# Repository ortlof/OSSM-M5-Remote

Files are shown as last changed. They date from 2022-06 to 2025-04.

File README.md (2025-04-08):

# Project OSSM M5 REMOTE
## Overview of the OSSM-M5-Remote

A Remote Control Platform for all ESP Controlled Sex Toys,with a focus on the [OSSM](https://github.com/KinkyMakers/OSSM-hardware) and related toys.

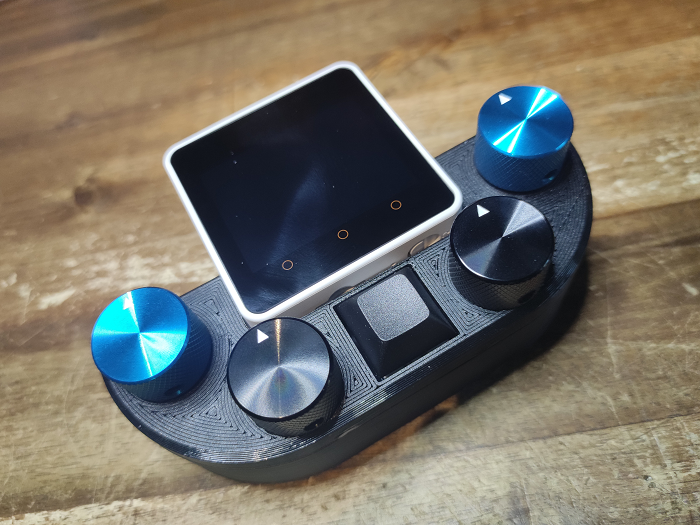
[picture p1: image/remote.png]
Final Addon Remote


Intially developed for the OSSM Project: 
https://github.com/KinkyMakers/OSSM-hardware

To help with development and design join the KinkyMakers Discord: https://discord.gg/MmpT9xE . Be sure to say hello in the #m5-remote channel. 

## !!! It does not Work with the Official OSSM Firmware !!!
This Branch is needed: https://github.com/ortlof/OSSM-Stroke

The Cable remote is obsolete with this firmware. If you want to go back you need to flash the OSSM orginal firmware back.

You can Easy flash the OSSM Mainboard with this [Online Flasher](https://openlust.org/lust-remote/lustremote-firmware/).

## Supported in this version of the M5 remote:
| OSSM Machine | https://github.com/KinkyMakers/OSSM-hardware |

## Not Supported sex toys in this version

| EJECT | https://github.com/ortlof/EJECT-cum-tube-project | [A Work in Progress]

# Build the OSSM M5 Remote Yourself

### Assembly instructions: [Klick Here !](Assembly.md)

## Bill Of Materials for sourcing Electrical Components

All M5Stack Core2 and CoreS3 are supported Now.

BOM is on Octopart for Easy Sourcing: https://octopart.com/bom-tool/rURYMuwB

PCB Files are located in the /OSSM-M5-Remote/Hardware/PCB folder if you want to make one yourself or use a different manufacturer other than PCBWay.

## Additional parts needed that are not PCB:  

| Quantity | Part | Sourcing EU | Price € |
|---|---|---|---|
| 1x | M5Stack CoreS3 SE | https://www.digikey.de/de/products/detail/m5stack-technology-co-ltd/K128-SE/23628221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 | 43 € |
| 2x | M3x25mm Hex Head Cap Bolt | https://www.amazon.de/Edelstahl-Innensechskant-Bolzenset-Eisenrahmen-Mechanischer-Innensechskantschraube-Mutternset/dp/B07PPFT871/ | 12,97 € |
| 4x | M3x20mm Hex Head Cap Bolt | Comes as part of the set mentioned above | " | 
| 4x | Heat Set inserts M3 | https://www.amazon.de/ruthex-Gewindeeinsatz-St%C3%BCck-Gewindebuchsen-Kunststoffteile/dp/B08BCRZZS3 | 8,99 € |
| 1x | 3,7v 2000mAh Lipo Batterie Size 34,5 mm x 10,6 mm x 56 mm | https://www.amazon.de/EEMB-103454-2AhLithium-Schutzplatine-Isolationsbeschichtung/dp/B08214DJLJ/ | 14,89 € |
| 4x | Encoder Knob Bought or 3D Printed | https://de.aliexpress.com/item/1005001394286414.html | 5 € |
| 1x | OSSM M5 Remote PCB | KinyMaker Discord #M5-Remote Channel or https://www.pcbway.com/project/shareproject/M5Stack_Core2_Remote_Plattform_2cb5bac0.html | 15 € |

--------------------------------------------

| Quantity | Part | Sourcing US | Price $ |
|---|---|---|---|
| 1x | M5Stack CoreS3 SE | https://www.digikey.de/de/products/detail/m5stack-technology-co-ltd/K128-SE/23628221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 | $47|
| 2x | M3x25mm Hex Head Cap Bolt | https://www.amazon.com/dp/B09NR8X2LV | $17.99 |
| 4x | M3x20mm Hex Head Cap Bolt | Comes as part of the set mentioned above | " | 
| 4x | Heat Set inserts M3 | https://www.amazon.com/ruthex-M3-Threaded-Inserts-RX-M3x5-7/dp/B08BCRZZS3 | $10.99 |
| 1x | 3.7v 2000mAh Lipo Battery Size 34.5 X 56 X 10.6 mm (The wires will need to be reversed in the connector on this one! See Assembly instructions for more info.) | https://www.amazon.com/EEMB-2000mAh-Battery-Rechargeable-Connector/dp/B08214DJLJ/ | $14.99 |
| 4x | Encoder Knob Bought or 3D Printed | https://www.aliexpress.us/item/3256801207971662.html?gatewayAdapt=deu2usa4itemAdapt | $5.00 |
| 1x | M5 Remote PCB | KinyMaker Discord #M5-Remote Channel or https://www.pcbway.com/project/shareproject/M5Stack_Core2_Remote_Plattform_2cb5bac0.html | $30.00 |

## 3D Printed Parts Needed:

| Quantity | Part | Information |
|---|---|---|
| 1x | Bottom.stl or Bottom_Adafruit_LIPO.stl or Bottom-Magnets.stl| There is a specific version for the wider Adafruit LIPO battery. Print with the base side facing down, 6 walls 20% Infill | 
| 1x | TOP-*-Keycap-Standoff.stl | Top Depends on your Keycap: Cherry or DSA (DSA is wider) | 
| 4x | M5_Remote_Knob_Customizable.scad | If you go for the 3d Printed knobs |

Filament - A good quality PLA works well. While there are no threads it is recommended that your printer is well calibrated.  

## Operation, or how do I use it?

1. Power on the OSSM and let it home.
2. Power on the OSSM M5 Remote.
3. Press the left encoder to select 'Connect'
4. You can verify it is connected by looking in the top left corner, it should say 'connected'.
5. You can now begin use. You'll need to set the speed, depth and stroke to more than 0 and press the middle key to start. Start the speed out slow.

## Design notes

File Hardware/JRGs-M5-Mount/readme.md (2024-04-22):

# JRGs M5 Mount

Hardware needed: 

| Quantity | Part |
|---|---|
| 2x | m3x12 Hex Head Cap Bolt |
| 2x | m5x20 Hex Head Cap Bolt |
| 2x | T-Slot Nut M5 | 

Print Without Supports

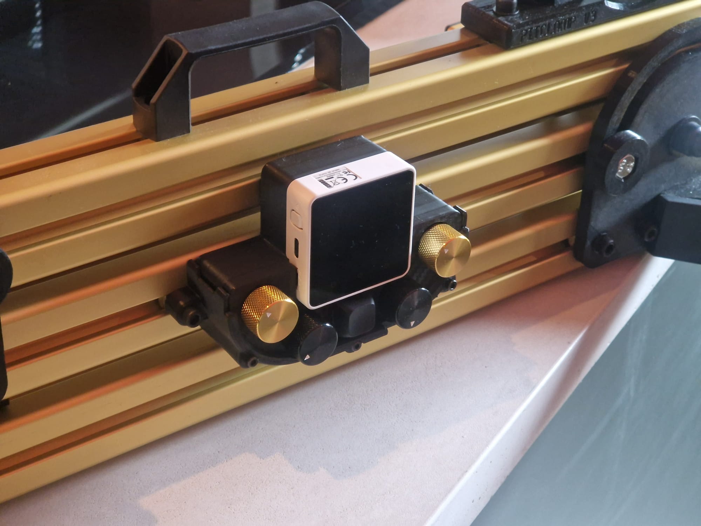
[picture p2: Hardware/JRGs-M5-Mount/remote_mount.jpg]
Mount


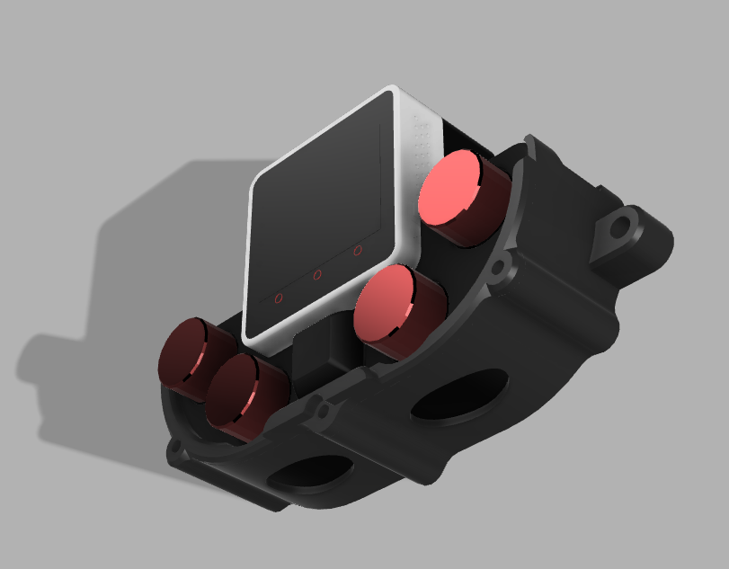
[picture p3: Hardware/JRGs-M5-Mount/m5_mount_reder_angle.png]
Mount


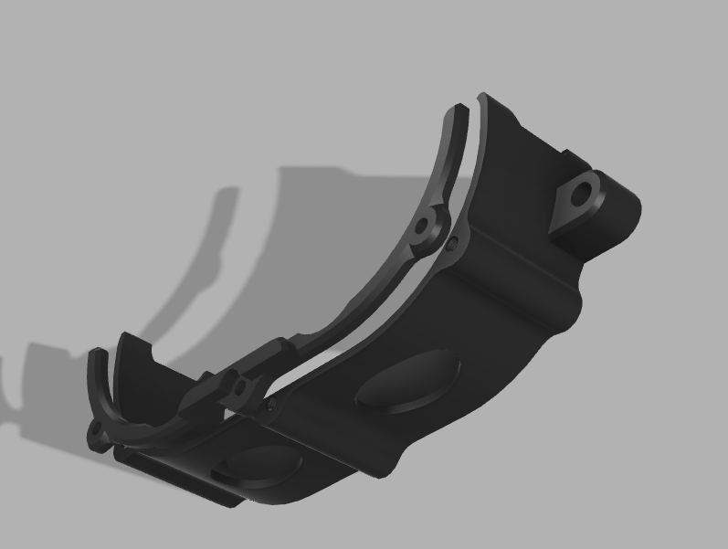
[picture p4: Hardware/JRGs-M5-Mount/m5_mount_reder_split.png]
Mount


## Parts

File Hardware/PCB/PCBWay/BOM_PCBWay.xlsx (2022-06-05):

 |  |  | T-H9W237108A
Item # | *Designator | *Qty | Manufacturer | *Mfg Part # | Description / Value | *Package/Footprint | Type | Your Instructions / Notes
1 | R1-R11 | 11 | Bourns | CR1206-JW-103ELF | Thick Film Resistors 10 kOhms 250 mW (1/4 W) | 3216 mm | SMD
Need a quick and accurante quote? Need an efficient production? Please read SMT Ordering Necessary Files & Info in 1 minute. Thank you very much! (https://www.pcbway.com/smt_ordering_guide.html)
Click for Instructions on How to Create a BOM (https://www.pcbway.com/blog/PCB_Assembly/How_to_Build_a_BOM__Bill_Of_Materials_.html)

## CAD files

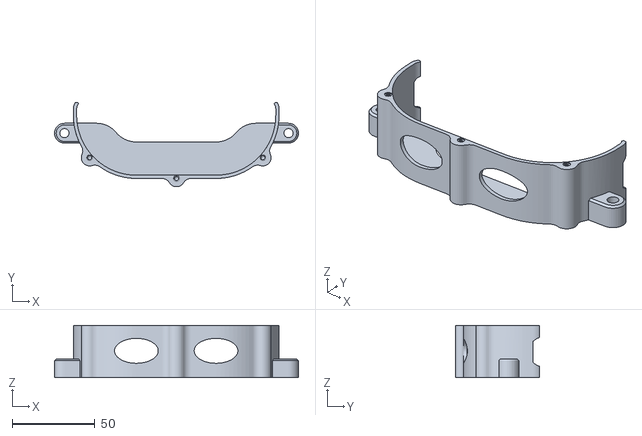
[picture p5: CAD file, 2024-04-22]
Hardware/JRGs-M5-Mount/Main_part_M5_mount.stl
147.1 x 50.9 x 31.6

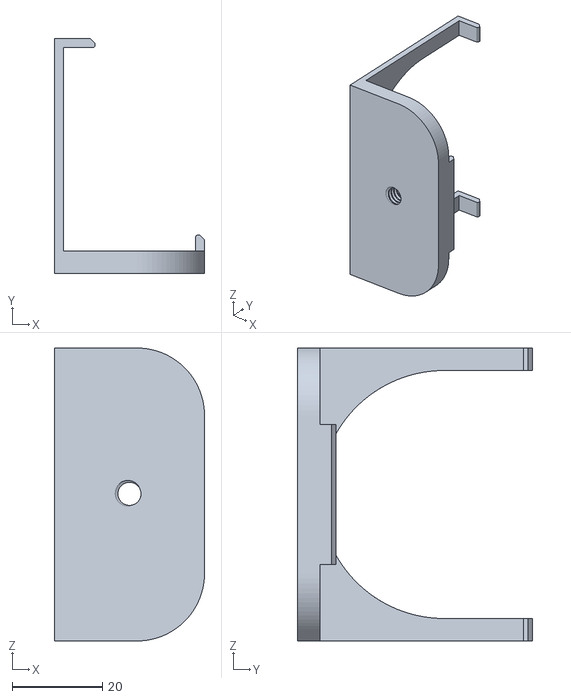
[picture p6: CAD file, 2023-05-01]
Hardware/Case/GHHOSS_tripod_mount/M5_Tripod_Holder_v3.stl
33.3 x 52.1 x 65.0

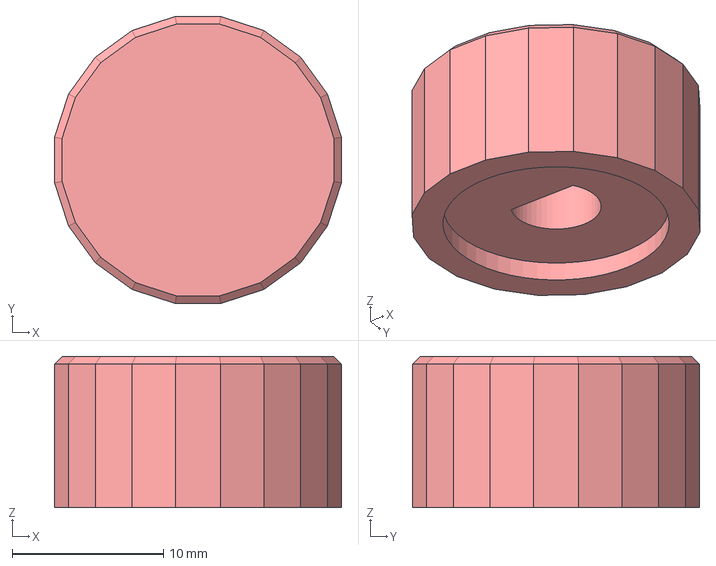
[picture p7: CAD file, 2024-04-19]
Hardware/Case/M5-Remote_knob_with_offset.step
19.0 x 19.0 x 10.0 mm

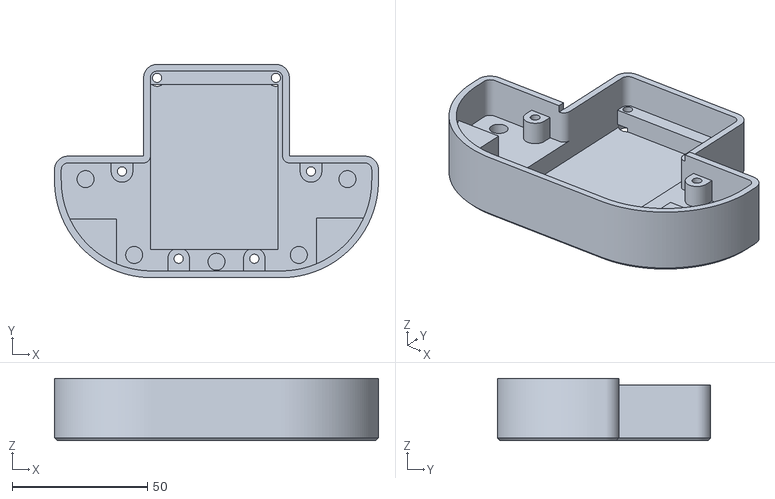
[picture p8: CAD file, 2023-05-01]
Hardware/Case/Bottom-Magnets.stl
120.0 x 79.0 x 23.0

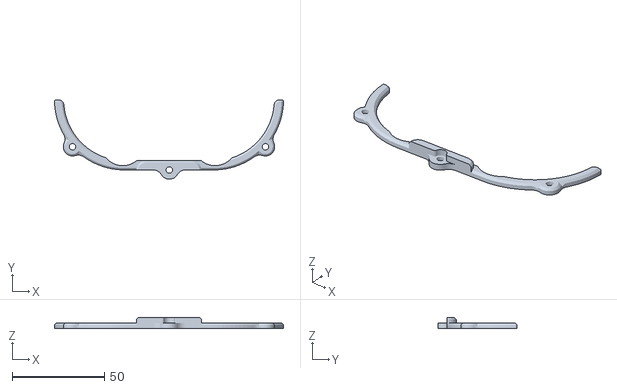
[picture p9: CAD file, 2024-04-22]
Hardware/JRGs-M5-Mount/top_part_m5_remote.stl
124.0 x 43.0 x 6.00

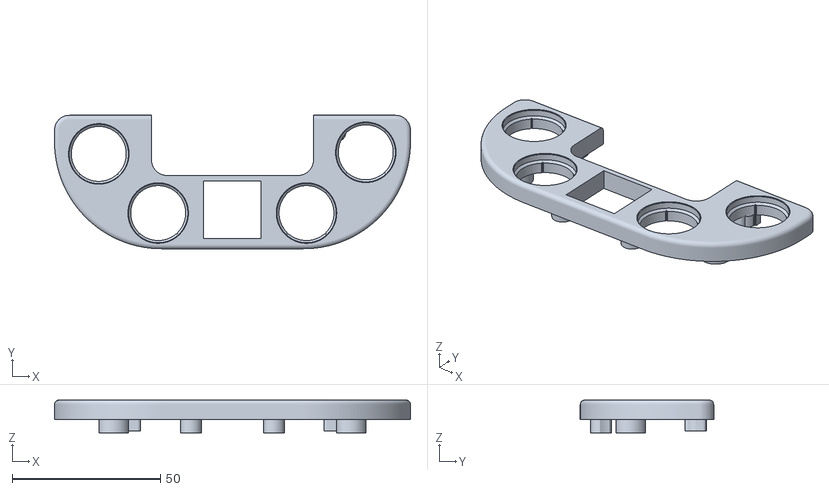
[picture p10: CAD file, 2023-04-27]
Hardware/Case/TOP-DSA-Keycap-Standoff_Bigger_Ecoder_Space.stl
120.0 x 45.0 x 11.1

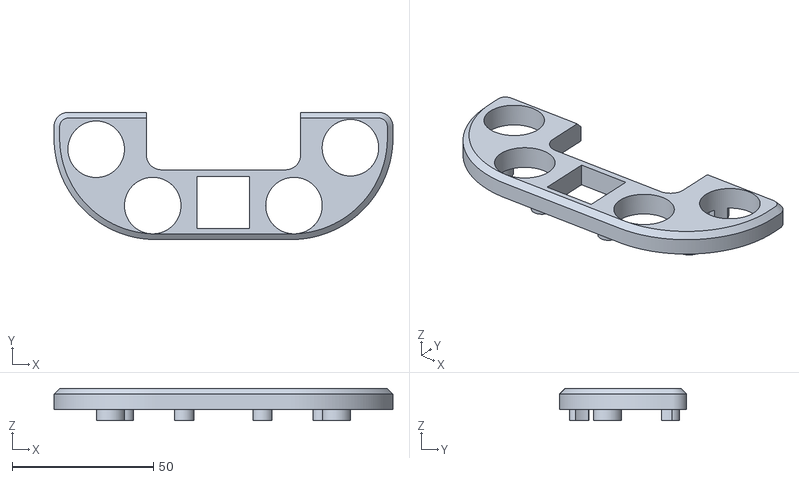
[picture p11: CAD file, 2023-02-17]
Hardware/Case/TOP-Cherry-Keycap-Standoff_Bigger_Ecoder_Space.stl
120.0 x 45.0 x 11.4

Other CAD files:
Hardware/Case/Bottom_Adafruit_Lipo.stl
Hardware/Case/TOP-DSA-Keycap-Standoff.stl
Hardware/Case/TOP-Cherry-Keycap-Standoff.stl
Hardware/Case/Bottom.stl
Hardware/Case/GHHOSS_tripod_mount/M5_Tripod_Holder_v3.f3d

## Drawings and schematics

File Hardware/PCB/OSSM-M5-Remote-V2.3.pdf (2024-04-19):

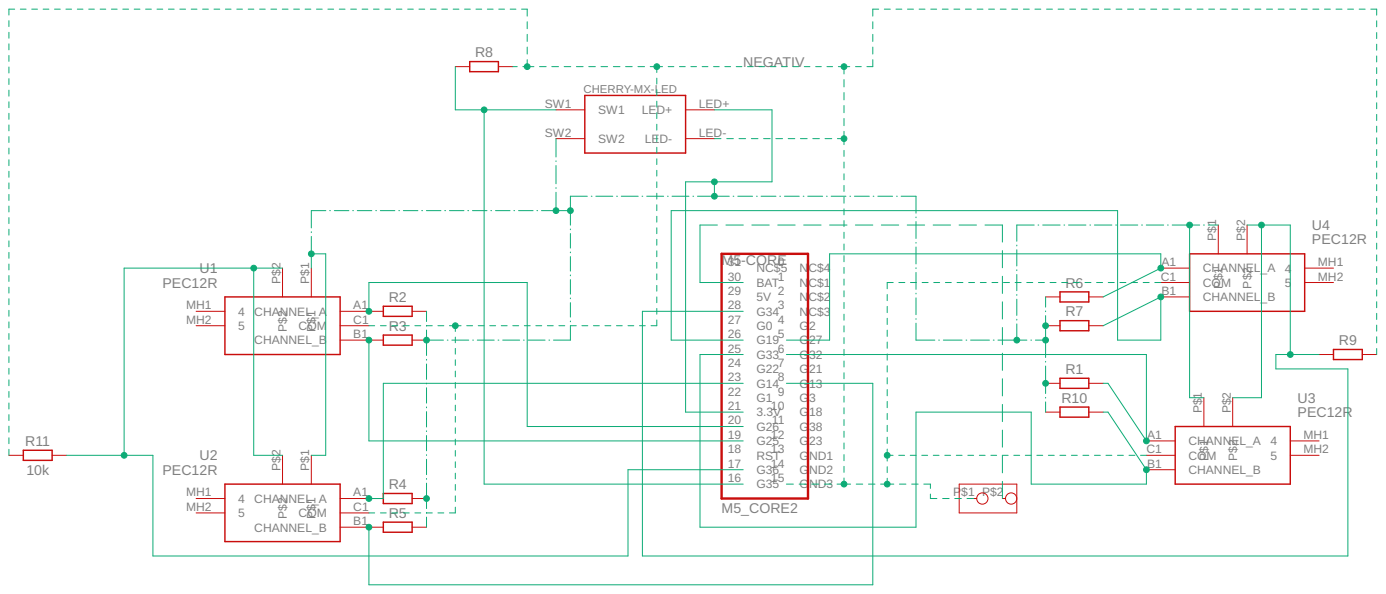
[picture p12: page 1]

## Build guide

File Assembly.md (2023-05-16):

# Assembling the OSSM M5 Remote

**Some important notes**
* Assembly will require soldering of small surface mount components in addition to through hole components. Be sure you have the proper tools and supplies:
    * Solder reflow oven or hot air gun with nozzles. You can use an old toaster oven as a reflow oven, just do not use it for food again after that.
    * Low temperature solder paste
    * Tweezers
    * Soldering iron
    * Rosin core solder
    * Flux
    * optional helping hands to hold the PCB while you solder
    * optional stencil provided by the PCB Manufacturer (not necessary but would make things easier)

* Due to a lack of standardisation in LIPO battery polarity it is important to verify how yours is configured. If the battery is reversed it will result in the CORE M5 Stack being damaged. You may have to reverse the female pins in the connector so they align with the expected polarity on the PCB.

## Solder the components

1. If you purchased a stencil from PCBWay/ Your chosen PCB Manufacturer, align it over the PCB and tape it in place. Add a blob of low temperature solder paste to the stencil and scrape it across the holes with a credit card or similar. When you lift the stencil away the PCB should now have solder paste on it in the correct places. Example photos below are from PCBWay and are not of the OSSM M5 Remote PCB  

solderPaste
solderPaste2
solderpaste3

If you did not purchase a stencil then you will need to very carefully coat the solder pads of the PCB with solder paste. It doesn't need a ton.

without_stencil  

Photo Credit Xue Ming. The amount of solder paste in the above photo is a little excessive.

2. Carefully place the 11 10k ohm resistors (Bourns CR1206-JW-103ELF) on the solder paste using tweezers. The polarity doesn't matter. Apply heat using a heat gun or reflow oven. The solder paste container will state what temperature to use.  

Resistors

3. Next, place the button encoders (Bourns PEC12R-4220F-S0024) at U1 and U4. Add flux to the pins and pad and solder the button encoders in place with a soldering iron.

4. Repeat the same for U2 and U3, adding flux and soldering the regular encoders (Bourns PEC12R-4220F-N0024)

5. The (Cherry MX1A-F1NN /  switch is soldered to the center position in the white square.

6. Next, the headers. Insert the headers from the front of the PCB (Amphenol Communications Solution 10129381-916001BLF), add a generous amount of flux to the back side and solder each pin.  

PCB-Soldered

7. Finally we will solder the battery connector (JST S2B-PH-K-S(LF)(SN)) on the back side of the PCB. The positive pin is the pin closest to the bottom edge of the PCB, the negative pin is the pin the closest to the top edge of the PCB.  

BatteryConnectorSoldered

8. Again pay special attention to the polarity of the Lithum battery you have, checking to see if the negative terminal of the battery connector will align with the negative pin of the connector on the PCB. Remove the wires from the battery terminal and reverse them if you need to (I had to, for example).

FlippingWires

## 3D printed parts

All parts are printed with 6 walls and 20% infill with a .04 nozzle. No supports and no brim (just a skirt).

A good quality PLA works well. While there are no threads it is recommended that your printer is well calibrated.  

* Be sure to choose the correct back to print based on the battery that you source 

    USA - Adafruit 485-2011 / or [Alternate](https://www.amazon.com/EEMB-2000mAh-Battery-Rechargeable-Connector/dp/B08214DJLJ/) uses 'Bottom_Adafruit_Lipo.stl' OR you can use 'Bottom-Magnets.stl' if you want to add 6 x 3mm magnets.

    Other countries - [RS Pro 1449405](https://uk.rs-online.com/web/p/speciality-size-rechargeable-batteries/1449405) uses 'Bottom.stl', or if you want to use magnets in the base you can use 'Bottom-Magnets.stl' that will accept 6 x 3mm magnets.

* You have options for the top depending on the keycap type you choose (cherry vs DSA). 

    If you chose to buy a DSA keycap go with 'TOP-DSA-Keycap-Standoff_Bigger_Ecoder_Space.stl'

    If you chose to buy a Cherry Keycap go with 'TOP-Cherry-Keycap-Standoff_Bigger_Ecoder_Space.stl'

* You can print encoder knobs or purchaes separate ones, 'M5_Remote_Knob_Customizable.scad'

* If you would like to mount the OSSM M5 remote to a mini tripod you can print the excellent holder by KinkyMakers Discord community member GHHOSS, the file is called  'M5_Tripod_Holder_v3.stl' and can be found in the 'GHHOSS_tripod_mount' folder.

* Finally you will add the M3 brass heatset inserts to the underside of the **TOP** piece.

## Final Assembly

1. Remove the M5 Core2 MIC/MPU Module from M5 Core2 Bottom, then unscrew the grey bottom and remove internal battery. Store the screws, the back and battery somewhere in case you want to use the M5 Stack Core2 for another project later.

2. Affix the battery to the bottom case with double sided tape.

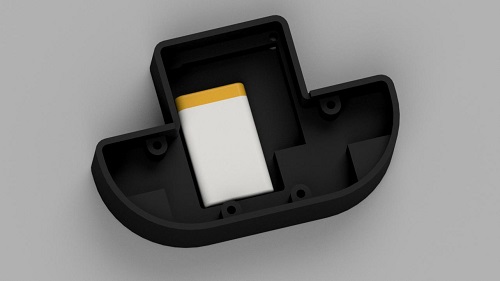
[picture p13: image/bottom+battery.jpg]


3. Connect Battery to PCB connector on the back side of the PCB.

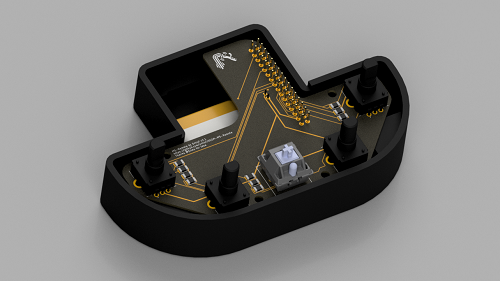
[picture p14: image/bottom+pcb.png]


4. Insert the PCB into Bottom case. 
AffixBattery

5. Connect the M5 Core2 to the headers on the PCB and fasten with two 25mm M3 Bolts to Case.

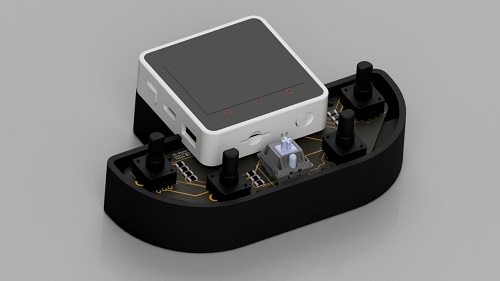
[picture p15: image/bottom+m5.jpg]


6. Put top on Remote and fasten with four M3 20mm Bolts to the Case.

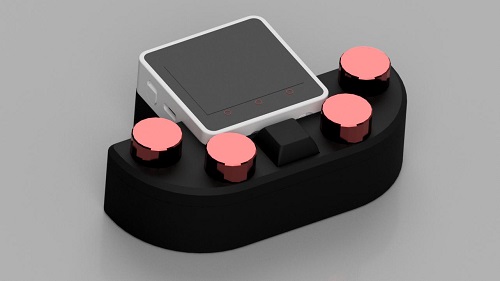
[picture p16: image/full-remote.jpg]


7. Install the Mx Cap and Encoder Knobs.

8. Charge the battery fully.

## Upload Software

1. Visit the [M5 website to download and install the drivers](https://docs.m5stack.com/en/core/core2) for the Core2 on your machine.

2. Clone or download this repository. If you download it as a zip, extract the files.  
**Note:** If you are one of the very small number of Version 1 PCB users, you will need to change your version to V1 in the config.h. The current version in this repository is V2.

3. Download Visual Studio Code and set up [PlatformIO](https://docs.platformio.org/en/latest/integration/ide/vscode.html#installation)  or [if you would prefer to watch a video](https://docs.platformio.org/en/latest/integration/ide/vscode.html#installation) - Thanks KinkyMakers Disord community admin Ka D'argo for the video!

Open the OSSM M5 Controller repository from step 2 in VS Code by clicking "File" > "Open Folder" and selecting the folder.

4. Once PlatformIO is set up you can select the M5 Core2 from your list of devices by clicking the 'Auto' button at the bottom center of the screen in the blue ribbon. If you aren't sure which device is the Core2 you can open DeviceManager on Windows and expand "Ports (COM & LPT)", then unplug the Core2 and plug it in again while keeping an eye on Device Manager to see what changes.

__Note:__
If you are one of the very small number of Version 1 PCB users, you will need to change your version to V1 in the config.h file. The current version in this GitHub repository is V2.

5. Click the upload button at the bottom left of the screen. The program will build then automatically upload to the M5 Core2. Once the software has succesfully uploaded you may disconnect the Core2 from your computer.

6. Next, Clone or download the M5 fork of the OSSM Stroke Engine from [here](https://github.com/ortlof/OSSM-Stroke) using the same method as mentioned in Step 2.

7. Open the OSSM Stroke repository from Step 5 in VS Code, again by clicking "File" > "Open Folder" and selecting the folder.

8. Now connect the OSSM board to your computer using a USB cable. You can look for it in DeviceManager the same way as you did in step 4. [You can also reference this link for help](https://github.com/KinkyMakers/OSSM-hardware/blob/master/OSSM%20PlatformIO%20Readme.md)

9. Click upload.

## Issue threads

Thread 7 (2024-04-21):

Ossm not using full stroke length

MarcoB979, 2024-04-21:
Seems to be a known bug and Imight have found a 'quick fix'. When in ossmconfig you have to setup max stroke. I have a 450mm rail and ended up setting the max stroke at 400. Also I set the max user speed to 300 (don't know if that also is making a difference). Then in the m5 remote code in main.cpp line 133 and 134 this is hard coded so you have to change it there too with the same values. Now I got the whole of the rail length with both depth and stroke and works just fine. Solution would be that  in main.cpp the values are not hard coded but transferred using a variable.

ortlof, 2025-06-02:
Sorry for not responding read it forgot it. I will check this but could be fixed in latest commits already.

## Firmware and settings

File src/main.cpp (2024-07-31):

#pragma GCC optimize ("Ofast")
#include <M5Unified.h>
#include <ESP32Encoder.h>
#include <esp_now.h>
#include <WiFi.h>
#include <PatternMath.h>
#include "OneButton.h"          //For Button Debounce and Longpress
#include "config.h"
#include <Arduino.h>
#include <Wire.h>
#include <lvgl.h>
#include <SPI.h>
#include "ui/ui.h"
#include <EEPROM.h>
#include "main.h"

#define LV_CONF_INCLUDE_SIMPLE
#include <lvgl.h>
#include <esp_timer.h>

constexpr int32_t HOR_RES=320;
constexpr int32_t VER_RES=240;

///////////////////////////////////////////
////
////  To Debug or not to Debug
////
///////////////////////////////////////////

// Uncomment the following line if you wish to print DEBUG info
#define DEBUG 

#ifdef DEBUG
#define LogDebug(...) Serial.println(__VA_ARGS__)
#define LogDebugFormatted(...) Serial.printf(__VA_ARGS__)
#else
#define LogDebug(...) ((void)0)
#define LogDebugFormatted(...) ((void)0)
#endif

#define OFF 0.0
#define ON 1.0

// Screens 

#define ST_UI_START 0
#define ST_UI_HOME 1

#define ST_UI_MENUE 10
#define ST_UI_PATTERN 11
#define ST_UI_Torqe 12
#define ST_UI_EJECTSETTINGS 13

#define ST_UI_SETTINGS 20

int st_screens = ST_UI_START;



// Menü States

#define CONNECT 0
#define HOME 1
#define MENUE 2
#define MENUE2 3
#define TORQE 4
#define PATTERN_MENUE 5
#define PATTERN_MENUE2 6
#define PATTERN_MENUE3 7
#define CUM_MENUE 20

int menuestatus = CONNECT;

// EEPROM Area:

#define EJECT 0
#define DARKMODE 1
#define VIBRATE 2
#define LEFTY 6

bool eject_status = false;
bool dark_mode = false;
bool vibrate_mode = true;
bool touch_home = false;
bool touch_disabled = false;

// Command States
#define CONN 0
#define SPEED 1
#define DEPTH 2
#define STROKE 3
#define SENSATION 4
#define PATTERN 5
#define TORQE_F 6
#define TORQE_R 7
#define OFF 10
#define ON  11
#define SETUP_D_I 12
#define SETUP_D_I_F 13
#define REBOOT 14

#define CUMSPEED 20
#define CUMTIME 21
#define CUMSIZE   22
#define CUMACCEL  23

#define CONNECT 88
#define HEARTBEAT 99

int displaywidth;
int displayheight;
int progheight = 30;
int distheight = 10;
int S1Pos;
int S2Pos;
int S3Pos;
int S4Pos;
bool rstate = false;
int pattern = 2;
char patternstr[20];
bool onoff = false;


long speedenc = 0;
long depthenc = 0;
long strokeenc = 0;
long sensationenc = 0;
long torqe_f_enc = 0;
long torqe_r_enc = 0;
long cum_t_enc = 0;
long cum_si_enc =0;
long cum_s_enc = 0;
long cum_a_enc = 0;
long encoder4_enc = 0;

extern float maxdepthinmm = 400.0;
extern float speedlimit = 600;
int speedscale = -5;

float speed = 0.0;
float depth = 0.0;
float stroke = 0.0;
float sensation = 0.0;
float torqe_f = 100.0;
float torqe_r = -180.0;
float cum_time = 0.0;
float cum_speed = 0.0;
float cum_size = 0.0;
float cum_accel = 0.0;

ESP32Encoder encoder1;
ESP32Encoder encoder2;
ESP32Encoder encoder3;
ESP32Encoder encoder4;

// Variable to store if sending data was successful
String success;

float out_esp_speed;
float out_esp_depth;
float out_esp_stroke;
float out_esp_sensation;
float out_esp_pattern;
bool out_esp_rstate;
bool out_esp_connected;
int out_esp_command;
float out_esp_value;
int out_esp_target;

float incoming_esp_speed;
float incoming_esp_depth;
float incoming_esp_stroke;
float incoming_esp_sensation;
float incoming_esp_pattern;
bool incoming_esp_rstate;
bool incoming_esp_connected;
bool incoming_esp_heartbeat;
int incoming_esp_target;

typedef struct struct_message {
  float esp_speed;
  float esp_depth;
  float esp_stroke;
  float esp_sensation;
  float esp_pattern;
  bool esp_rstate;
  bool esp_connected;
  bool esp_heartbeat;
  int esp_command;
  float esp_value;
  int esp_target;
} struct_message;

bool Ossm_paired = false;

struct_message outgoingcontrol;
struct_message incomingcontrol;

esp_now_peer_info_t peerInfo;
uint8_t OSSM_Address[] = {0xFF, 0xFF, 0xFF, 0xFF, 0xFF, 0xFF}; // Broadcast to all ESP32s, upon connection gets updated to the actual address

#define HEARTBEAT_INTERVAL 5000/portTICK_PERIOD_MS	// 5 seconds

// Bool

bool EJECT_On = false;
bool OSSM_On = false;

#define EEPROM_SIZE 200

// Tasks:

TaskHandle_t eRemote_t  = nullptr;  // Esp Now Remote Task

void espNowRemoteTask(void *pvParameters); // Handels the EspNow Remote
bool connectbtn(); //Handels Connectbtn
int64_t touchmenue();
void vibrate();
void mxclick();
bool mxclick_short_waspressed = false;
void mxlong();
bool mxclick_long_waspressed = false;
void click2();
bool click2_short_waspressed = false;
void click3();
bool click3_short_waspressed = false;

lv_display_t *display;
lv_indev_t *indev;

static lv_draw_buf_t *draw_buf1;
static lv_draw_buf_t *draw_buf2;

// Display flushing
void my_display_flush(lv_display_t *disp, const lv_area_t *area, uint8_t *px_map) {
  uint32_t w = (area->x2 - area->x1 + 1);
  uint32_t h = (area->y2 - area->y1 + 1);

  lv_draw_sw_rgb565_swap(px_map, w*h);
  M5.Display.pushImageDMA<uint16_t>(area->x1, area->y1, w, h, (uint16_t *)px_map);
  lv_disp_flush_ready(disp);
}

uint32_t my_tick_function() {
  return (esp_timer_get_time() / 1000LL);
}

void my_touchpad_read(lv_indev_t * drv, lv_indev_data_t * data) {
  M5.update();
  auto count = M5.Touch.getCount();

  if ( count == 0 ) {
    data->state = LV_INDEV_STATE_RELEASED;
  } else {
    auto touch = M5.Touch.getDetail(0);
    data->state = LV_INDEV_STATE_PRESSED; 
    data->point.x = touch.x;
    data->point.y = touch.y;
  }
}

static void event_cb(lv_event_t *e)
{
  lv_event_code_t code = lv_event_get_code(e);
  lv_obj_t *label = reinterpret_cast<lv_obj_t *>(lv_event_get_user_data(e));

  switch (code)
  {
  case LV_EVENT_PRESSED:
    lv_label_set_text(label, "The last button event:\nLV_EVENT_PRESSED");
    break;
  case LV_EVENT_CLICKED:
    lv_label_set_text(label, "The last button event:\nLV_EVENT_CLICKED");
    break;
  case LV_EVENT_LONG_PRESSED:
    lv_label_set_text(label, "The last button event:\nLV_EVENT_LONG_PRESSED");
    break;
  case LV_EVENT_LONG_PRESSED_REPEAT:
    lv_label_set_text(label, "The last button event:\nLV_EVENT_LONG_PRESSED_REPEAT");
    break;
  default:
    break;
  }
}



void OnDataSent(const uint8_t *mac_addr, esp_now_send_status_t status) {
}

void OnDataRecv(const uint8_t * mac, const uint8_t *incomingData, int len) {
  memcpy(&incomingcontrol, incomingData, sizeof(incomingcontrol));

  if(incomingcontrol.esp_target == M5_ID && Ossm_paired == false){

    // Remove the existing peer (0xFF:0xFF:0xFF:0xFF:0xFF:0xFF)
    esp_err_t result = esp_now_del_peer(peerInfo.peer_addr);

    if (result == ESP_OK) {

      memcpy(OSSM_Address, mac, 6); //get the mac address of the sender
      
      // Add the new peer
      memcpy(peerInfo.peer_addr, OSSM_Address, 6);
      if (esp_now_add_peer(&peerInfo) == ESP_OK) {
        LogDebugFormatted("New peer added successfully, OSSM addresss : %02X:%02X:%02X:%02X:%02X:%02X\n", OSSM_Address[0], OSSM_Address[1], OSSM_Address[2], OSSM_Address[3], OSSM_Address[4], OSSM_Address[5]);
        Ossm_paired = true;
      }
      else {
        LogDebug("Failed to add new peer");
      }
    }
    else {
      LogDebug("Failed to remove peer");
    }

    
    if(incomingcontrol.esp_speed > speedlimit){
      speedlimit = 600;
    } else (
    speedlimit = incomingcontrol.esp_speed);
    LogDebug(speedlimit);
    maxdepthinmm = incomingcontrol.esp_depth;
    LogDebug(maxdepthinmm);
    pattern = incomingcontrol.esp_pattern;
    LogDebug(pattern);
    outgoingcontrol.esp_target = OSSM_ID;
    
    result = esp_now_send(OSSM_Address, (uint8_t *) &outgoingcontrol, sizeof(outgoingcontrol));
    LogDebug(result);
    
    if (result == ESP_OK) {
      Ossm_paired = true;
      lv_label_set_text(ui_connect, "Connected");
      lv_scr_load_anim(ui_Home, LV_SCR_LOAD_ANIM_FADE_ON,20,0,false);
    }
  }
  switch(incomingcontrol.esp_command)
    {
    case OFF: 
    {
    OSSM_On = false;
    }
    break;
    case ON:
    {
    OSSM_On = true;
    }
    break;
    }
}

//Sends Commands and Value to Remote device returns ture or false if sended
bool SendCommand(int Command, float Value, int Target){
  
  if(Ossm_paired == true){

    outgoingcontrol.esp_connected = true;
    outgoingcontrol.esp_command = Command;
    outgoingcontrol.esp_value = Value;
    outgoingcontrol.esp_target = Target;
    esp_err_t result = esp_now_send(OSSM_Address, (uint8_t *) &outgoingcontrol, sizeof(outgoingcontrol));
  
    if (result == ESP_OK) {
      return true;
    } 
    else {
      delay(20);
      esp_err_t result = esp_now_send(OSSM_Address, (uint8_t *) &outgoingcontrol, sizeof(outgoingcontrol));
      return false;
    }
  }
}

void connectbutton(lv_event_t * e)
{
    if(!Ossm_paired){
      outgoingcontrol.esp_command = HEARTBEAT;
      outgoingcontrol.esp_heartbeat = true;
      outgoingcontrol.esp_target = OSSM_ID;
      esp_err_t result = esp_now_send(OSSM_Address, (uint8_t *) &outgoingcontrol, sizeof(outgoingcontrol));
    }
}

void savesettings(lv_event_t * e)
{
	if(lv_obj_get_state(ui_ejectaddon) == 1){
		EEPROM.writeBool(EJECT,true);
	} else if(lv_obj_get_state(ui_ejectaddon) == 0){
		EEPROM.writeBool(EJECT,false);
	}
  if(lv_obj_get_state(ui_darkmode) == 1){
		EEPROM.writeBool(DARKMODE,true);
	} else if(lv_obj_get_state(ui_darkmode) == 0){
		EEPROM.writeBool(DARKMODE,false);
	}
  if(lv_obj_get_state(ui_vibrate) == 1){
		EEPROM.writeBool(VIBRATE,true);
	} else if(lv_obj_get_state(ui_vibrate) == 0){
		EEPROM.writeBool(VIBRATE,false);
	}
  if(lv_obj_get_state(ui_lefty) == 1){
		EEPROM.writeBool(LEFTY,true);
	} else if(lv_obj_get_state(ui_lefty) == 0){
		EEPROM.writeBool(LEFTY,false);
	}
  EEPROM.commit();
  delay(100);
  ESP.restart();
}

void screenmachine(lv_event_t * e)
{
  if (lv_scr_act() == ui_Start){
    st_screens = ST_UI_START;
  } else if (lv_scr_act() == ui_Home){
    st_screens = ST_UI_HOME;
    speed = lv_slider_get_value(ui_homespeedslider);
    LogDebug(speedenc);
    LogDebug(speed);
    speedenc =  fscale(0.5, speedlimit, 0, Encoder_MAP, speed, 0);
    encoder1.setCount(speedenc); 
    LogDebug(speedenc);

    lv_slider_set_range(ui_homedepthslider, 0, maxdepthinmm);
    depth = lv_slider_get_value(ui_homedepthslider);       
    depthenc =  fscale(0, maxdepthinmm, 0, Encoder_MAP, depth, 0);
    encoder2.setCount(depthenc);

    lv_slider_set_range(ui_homestrokeslider, 0, maxdepthinmm);        
    stroke = lv_slider_get_value(ui_homestrokeslider);    
    strokeenc =  fscale(0, maxdepthinmm, 0, Encoder_MAP, stroke, 0);
    encoder3.setCount(strokeenc);

    sensation = lv_slider_get_value(ui_homesensationslider);
    sensationenc =  fscale(-100, 100, (Encoder_MAP/2*-1), (Encoder_MAP/2), sensation, 0);
    encoder4.setCount(sensationenc);        
            
  } else if (lv_scr_act() == ui_Menue){
    st_screens = ST_UI_MENUE;
  } else if (lv_scr_act() == ui_Pattern){
    st_screens = ST_UI_PATTERN;
  } else if (lv_scr_act() == ui_Torqe){
    st_screens = ST_UI_Torqe;
    torqe_f = lv_slider_get_value(ui_outtroqeslider);
    torqe_f_enc = fscale(50, 200, 0, Encoder_MAP, torqe_f, 0);
    encoder1.setCount(torqe_f_enc);

    torqe_r = lv_slider_get_value(ui_introqeslider);
    torqe_r_enc = fscale(20, 200, 0, Encoder_MAP, torqe_r, 0);
    encoder4.setCount(torqe_r_enc);

  } else if (lv_scr_act() == ui_EJECTSettings){
    st_screens = ST_UI_EJECTSETTINGS;
  } else if (lv_scr_act() == ui_Settings){
    st_screens = ST_UI_SETTINGS;
  }
}

void ejectcreampie(lv_event_t * e){
  if(EJECT_On == true){
    lv_obj_clear_state(ui_HomeButtonL, LV_STATE_CHECKED);
    EJECT_On = false;
  } else if(EJECT_On == false){
    lv_obj_add_state(ui_HomeButtonL, LV_STATE_CHECKED);
    EJECT_On = true;
  } 
}

void savepattern(lv_event_t * e){
  pattern = lv_roller_get_selected(ui_PatternS);
  lv_roller_get_selected_str(ui_PatternS,patternstr,0);
  lv_label_set_text(ui_HomePatternLabel,patternstr);
  LogDebug(pattern);
  float patterns = pattern;
  SendCommand(PATTERN, patterns, OSSM_ID);
}

void homebuttonmevent(lv_event_t * e){
  LogDebug("HomeButton");
  if(OSSM_On == false){
    SendCommand(ON, 0.0, OSSM_ID);
  } else if(OSSM_On == true){
    SendCommand(OFF, 0.0, OSSM_ID);
  }
}

void setupDepthInter(lv_event_t * e){
    SendCommand(SETUP_D_I, 0.0, OSSM_ID);
}

void setupdepthF(lv_event_t * e){
    SendCommand(SETUP_D_I_F, 0.0, OSSM_ID);
}

void setup(){
  auto cfg = M5.config();
  M5.begin(cfg);
  EEPROM.begin(EEPROM_SIZE);

  M5.Power.setChargeCurrent(BATTERY_CHARGE_CURRENT);
  LogDebug("\n Starting");      // Start LogDebug 

  WiFi.mode(WIFI_STA);
  LogDebug(WiFi.macAddress());

  // Init ESP-NOW
  if (esp_now_init() != ESP_OK) {
    Serial.println("Error initializing ESP-NOW");
  }
  // Once ESPNow is successfully Init, we will register for Send CB to
  // get the status of Trasnmitted packet
  esp_now_register_send_cb(OnDataSent);

  // register peer
  peerInfo.channel = 0;  
  peerInfo.encrypt = false;
  // register first peer  
  memcpy(peerInfo.peer_addr, OSSM_Address, 6);
  if (esp_now_add_peer(&peerInfo) != ESP_OK){
    Serial.println("Failed to add peer");
  }
  // Register for a callback function that will be called when data is received
  esp_now_register_recv_cb(OnDataRecv);

  xTaskCreatePinnedToCore(espNowRemoteTask,      /* Task function. */
                            "espNowRemoteTask",  /* name of task. */
                            3096,               /* Stack size of task */
                            NULL,               /* parameter of the task */
                            5,                  /* priority of the task */
                            &eRemote_t,         /* Task handle to keep track of created task */
                            0);                 /* pin task to core 0 */
  delay(200);
  
  encoder1.attachHalfQuad(ENC_1_CLK, ENC_1_DT);
  encoder2.attachHalfQuad(ENC_2_CLK, ENC_2_DT);
  encoder3.attachHalfQuad(ENC_3_CLK, ENC_3_DT);
  encoder4.attachHalfQuad(ENC_4_CLK, ENC_4_DT);
  Button1.attachClick(mxclick);
  Button1.attachLongPressStop(mxlong);
  Button2.attachClick(click2);
  Button3.attachClick(click3);

    //****Load EEPROOM:
  eject_status = EEPROM.readBool(EJECT);
  dark_mode = EEPROM.readBool(DARKMODE);
  vibrate_mode = EEPROM.readBool(VIBRATE);
  touch_home = EEPROM.readBool(LEFTY);

  // Initialize `disp_buf` display buffer with the buffer(s).
  // lv_draw_buf_init(&draw_buf, LV_HOR_RES_MAX, LV_VER_RES_MAX);
  M5.Display.setEpdMode(epd_mode_t::epd_fastest); // fastest but very-low quality.
  if (M5.Display.width() < M5.Display.height())
  { /// Landscape mode.
  M5.Display.setRotation(M5.Display.getRotation() ^ 1);
  }
  
  lv_init();
  lv_tick_set_cb(my_tick_function);

  display = lv_display_create(HOR_RES, VER_RES);
  lv_display_set_flush_cb(display, my_display_flush);

  static lv_color_t buf1[HOR_RES * 15]; 
  lv_display_set_buffers(display, buf1, nullptr, sizeof(buf1), LV_DISPLAY_RENDER_MODE_PARTIAL);

  indev = lv_indev_create();
  lv_indev_set_type(indev, LV_INDEV_TYPE_POINTER);
  lv_indev_set_read_cb(indev, my_touchpad_read);
  ui_init();  

  if(eject_status == true){
  lv_obj_add_state(ui_ejectaddon, LV_STATE_CHECKED);
  lv_obj_clear_state(ui_EJECTSettingButton, LV_STATE_DISABLED);
  lv_obj_clear_state(ui_HomeButtonL, LV_STATE_DISABLED);
  }
  if(dark_mode == true){
  lv_obj_add_state(ui_darkmode, LV_STATE_CHECKED);
  }
  if(vibrate_mode == true){
  lv_obj_add_state(ui_vibrate, LV_STATE_CHECKED);
  }
  if(touch_home == true){
  lv_obj_add_state(ui_lefty, LV_STATE_CHECKED);
  }
  lv_roller_set_selected(ui_PatternS,2,LV_ANIM_OFF);
  lv_roller_get_selected_str(ui_PatternS,patternstr,0);
  lv_label_set_text(ui_HomePatternLabel,patternstr);


}
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

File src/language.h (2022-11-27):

//EN
// Language
#define T_HEADER            "OSSM Remote"
#define T_BLANK             ""
#define T_MENUE             "Menu"
#define T_DEMO              "Demo"
#define T_CONNECT           "Connect"
#define T_SETTINGS          "Settings"
#define T_MOTD              "Welcome to OSSM M5 Remote"
#define T_BATT              "Battery"
#define T_CREAMPIE          "Creampie"
#define T_START             "Start/Stop"
#define T_CUM               "Cum"
#define T_HOME              "Home"
#define T_MEN1              "Up"
#define T_MEN2              "Down"
#define T_SPEED             "Speed:"
#define T_DEPTH             "Depth:"
#define T_MM                " mm"
#define T_STROKE            "Stroke:"
#define T_SENSATION         "Sensation:"
#define T_SETUP_DEPTH_I     "Set Depth Interactively"
#define T_SETUP_DEPTH_F     "Set Depth Fancy"
#define T_SELECT_PATTERN    "Select Pattern"
#define T_PATTERN_Button    "Select Pattern \n Menue"
#define T_RESTART           "Restart"
#define T_SETUP_TORQE       "Setup Torque"
#define T_OUT_TORQE         "Outward Torque:"
#define T_IN_TORQE          "Inward Torque:"
#define T_EJECT_SETTINGS    "EJECT Settings"
#define T_EJECT             "EJECT"
#define T_SAVE              "Save"
#define T_LOW               "Low"
#define T_HIGH              "High"
#define T_DARKM             "Dark Mode"
#define T_VIBRATE           "Vibrate"
#define T_TOUCHSETTING      "Touch Disabled"


#define T_Patterns          "Pattern:"
#define T_SimpleStroke      "Simple Stroke"
#define T_TeasingPounding   "Teasing or Pounding"
#define T_RoboStroke        "Robo Stroke"
#define T_HalfnHalf         "Half 'n' Half"
#define T_Deeper            "Deeper"
#define T_StopNGo           "Stop'n'Go"
#define T_Insist            "Insist"
#define T_JackHammer        "Jack Hammer"
#define T_StrokeNibbler     "Stroke Nibbler"

#define T_CUM_SPEED         "CUM Speed"
#define T_CUM_TIME          "CUM Time"
#define T_CUM_Volume        "CUM Volume"
#define T_CUM_Accel         "CUM Force"

#define T_FUCKS_MIN         " F/m"

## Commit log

2022-03-27 Pattern Menue
    [Body.3mf, Knob.3mf, top.3mf]
2022-03-28 Updated f3ds und pcb export
    [BOM.xlsx, Body.3mf, Case-Body.3mf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]
2022-05-06 Readme, PCB, BOM
    Changed Readme, Removed Old BOM, Added PCB PDF Printout
    [BOM.xlsx]
2022-06-05 Final v2 PcB Desing
    Pin Changes in v2 PcB
    [BOM_PCBWay.xlsx, OSSM-M5-Remote-PCB-V2.f3z, OSSM-M5-Remote-V2-Centroid.csv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]
2022-07-14 Changed Case Files / Changed config.h
    Moved Pinlayout to config.h
    [Bottom.stl, Case-Body.3mf, Case-Top-With-Knobs.3mf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]
2022-07-17 Fixed Things
    Added MX/DSA keycap stl
    Fixed PCB hole size on JST Header
    Exported Newest f3z version
    [TOP-Cherry-Keycap.stl, TOP-DSA-Keycap.stl]
2022-07-21 Fixed PCB | Changed Case
    [TOP-Cherry-Keycap.stl, TOP-DSA-Keycap.stl]
2022-07-24 Standoff Fix and add scad for knob
    [M5_Remote_Knob_Customizable.scad, TOP-Cherry-Keycap-Standoff.stl, TOP-Cherry-Keycap.stl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]
2022-07-25 Fix Pattern Menue from Sapph1re Dra90n
    [main.cpp]
2022-07-31 Fixed Platformio & Adafruit Lipo case
    [Bottom_Adafruit_Lipo.stl]
2022-08-08 Buttons / Encoder
    Buttons & Encoder Online on Home and Menue. No activ use possible.
2022-08-11 Fixed Library Issue + More Screens Running
    [main.cpp]
2022-08-12 Fixed Pinout for V1 PCB's
2022-11-27 Added Line 134 scaling for speed
    Added Speedscale for better mapping of speed encoder
2023-01-26 Increase default charge current from 100mA to 960mA
2023-01-27 Change default charging current back to 100mA, but keep config
2023-02-17 Update on 3D Prints
    [TOP-Cherry-Keycap-Standoff_Bigger_Ecoder_Space.stl, TOP-DSA-Keycap-Standoff_Bigger_Ecoder_Space.stl]
2023-04-27 Add M5 Tripod Hodler
    Thanks to GHHoss
    [M5_Tripod_Holder_v2.3mf, M5_Tripod_Holder_v2.stl, TOP-DSA-Keycap-Standoff_Bigger_Ecoder_Space.stl]
2023-05-01 Update Tripod Holder & Fusion Export
    Fusion Export M5 Remote with Magnets
    [Bottom-Magnets.stl, M5_Tripod_Holder_v2.3mf, M5_Tripod_Holder_v2.stl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]
2023-05-14 expanding instructions
    Create assembly.md
    move a few headings from readme.md to assembly.md, add a US parts table
    to do: add pictures
2023-05-14 use instructions
    Added instructions for use as the current software requires a specific procedure to be followed to work correctly.
2023-05-15 Update Assembly.md
    Adding pictures and formatting changes
2023-05-15 Update README.md
    Linking the assembly instructions and clarifying points
2023-05-15 Update Assembly.md
    cleanup before PR
2023-06-03 V2.1 PCB Update
    Changed Silkscreen for Battery Pins
    Linked U3/U2 to enable change of pushbutton encoder place.
    [OSSM-M5-Remote-V2-PCB.f3z]
2023-06-10 Fix autoconnect Bug Remote.
    Fixed bug the Remotes autoconnects when running bevor the OSSM
    [main.cpp]
2023-06-15 Fix issue creampie button
2024-03-11 Fix Knob from DirkStrider
    Thanks DirkStrider for the fixed knob step
    [M5-Remote_knob_with_offset.step]
2024-03-14 Fixed 5v -> 3.3v Issues
2024-04-19 Update PCB Files
2024-04-22 Fix Readme + Upload Mount.
    [Main_part_M5_mount.stl, top_part_m5_remote.stl]
2024-07-31 V2.1.0
    Fixed MX Key Issues. Fixed Speed and Depth Display Issues.
    [main.cpp]
